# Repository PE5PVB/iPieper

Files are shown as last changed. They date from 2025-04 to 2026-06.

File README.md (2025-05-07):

# iPieper: Uitgebreide 2m FM vossenjacht zender

De iPieper is een laagvermogen PLL gestuurde FM-vossenjachtzender met WAV/MP3 geheugen. Ook kun je
verschillende instellingen programmeren, zoals hoe lang de zender ingeschakeld of uitgeschakeld moet zijn, welk
bestand moet worden afgespeeld en op welke frequentie er moet worden uitgezonden. Je kunt elke willekeurige
frequentie tussen 144 en 146MHz gebruiken in een raster van 25kHz. Het is ook mogelijk om de iPieper zelf een
frequentie te laten kiezen wanneer deze begint met uitzenden.

Ook is er een header aanwezig met een aantal GPIOs. Zo kun je bijvoorbeeld zelf sensoren aansluiten. De software en
hardware is geheel opensource dus naar gelieve aan te passen.

Programmeren gaat via het Bluetooth serial protocol. Wanneer de iPieper met bijvoorbeeld een Windows laptop via
bluetooth is verbonden zal er een virtuele COM-poort beschikbaar komen om deze te programmeren.

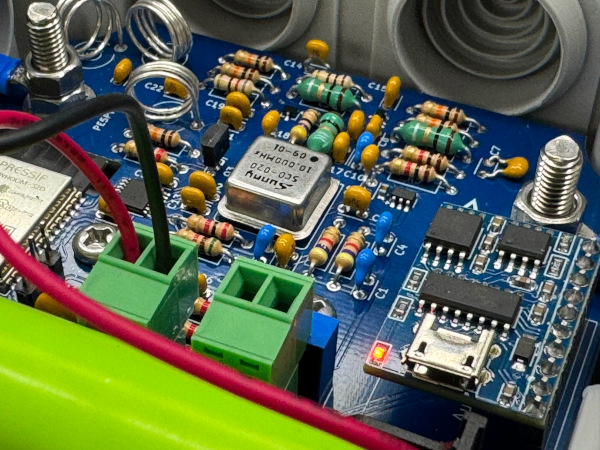
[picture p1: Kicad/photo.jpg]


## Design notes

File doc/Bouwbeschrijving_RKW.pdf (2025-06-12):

# Bouwproject iPieper

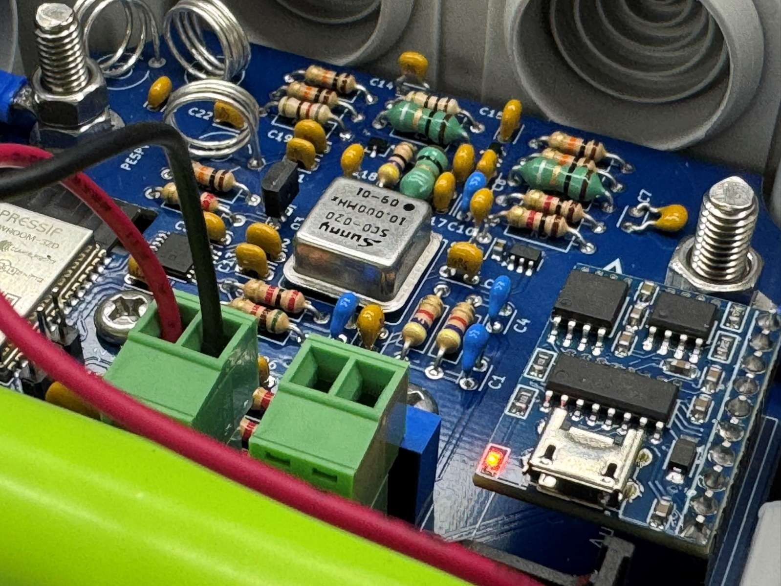
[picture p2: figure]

## VRZA Radiokampweek 2025

Sjef Verhoeven PE5PVB

## Inleiding

De iPieper is een laagvermogen PLL gestuurde FM-vossenjachtzender met WAV/MP3 geheugen. Ook kun je verschillende instellingen programmeren, zoals hoe lang de zender ingeschakeld of uitgeschakeld moet zijn, welk bestand moet worden afgespeeld en op welke frequene er moet worden uitgezonden. Je kunt elke willekeurige frequene tussen 144 en 146MHz gebruiken in een raster van 25kHz. Het is ook mogelijk om de iPieper zelf een frequene te laten kiezen wanneer deze begint met uitzenden.

Ook is er een header aanwezig met een aantal GPIOs. Zo kun je bijvoorbeeld zelf sensoren aansluiten. De soware en hardware is geheel opensource dus naar gelieve aan te passen.

Programmeren gaat via het Bluetooth serial protocol. Wanneer de iPieper met bijvoorbeeld een Windows laptop via bluetooth is verbonden zal er een virtuele COM-poort beschikbaar komen om deze te programmeren.

## Werking

Het 2-meter signaal wordt direct op frequene gegenereerd door U1, een oscillator die geïntegreerd is in een chip. Deze oscillator wordt aangestuurd door U2, het PLL IC. Na generae wordt het RF-signaal in twee stappen versterkt door Q1 en Q2, waarna het via een laagdoorlaailter naar de antenneklem wordt geleid. Terugkoppeling van het RF-signaal vindt plaats na de eerste buffertrap via C17, zodat de PLL een fasevergelijking kan uitvoeren. Op basis hiervan ontstaat een regelspanning die gefilterd wordt door het loopfilter, bestaande uit C1, C2, C3, R1 en R2. Het audiosignaal wordt via R3 en C4 gekoppeld aan deze regelspanning, wat resulteert in FM-modulae. Het niveau van dit audiosignaal is instelbaar met RV1, dat het signaal na een laagdoorlaailter (bestaande uit R18, R20, R21, C25 en C26) verwerkt.
De aansturing van de PLL wordt verzorgd door U3, een ESP32-module. Hoewel deze microcontroller in dit geval misschien wat overgekwalificeerd is, is hij zeer betaalbaar en bovendien voorzien van een ingebouwde Bluetoothmodule. Om het stroomverbruik te beperken, is de kloksnelheid tot een minimum gereduceerd. De ESP32 is ook in staat om een toon te genereren die gebruikt wordt in de “panic”-modus van de iPieper. Daarnaast schakelt hij via Q3, een FET, de gehele zender in of uit.
Voor de audio-opwekking wordt gebruikgemaakt van de JQ8400-FL module, die geplaatst wordt in J5. Wanneer je MP3- of WAV-bestanden wilt vervangen of toevoegen, moet deze module uit het voetje worden gehaald en rechtstreeks op een PC worden aangesloten. De module wordt dan herkend als een externe schijf. Ook deze audiomodule wordt aangestuurd door de ESP32.
De spanningsvoorziening is in handen van U4, een 3,3V spanningsregelaar met een uitzonderlijk lage dropoutspanning van maximaal 50 mV. Door J7 te overbruggen, kan de iPieper volledig worden uitgeschakeld.

## Verbinden via Bluetooth

Wanneer de iPieper in de programmeerstand is geschakeld (zie volgend hoofdstuk), kan deze worden verbonden via bluetooth. Met bijvoorbeeld een Windows laptop kun je rechtsonder (bij de klok) op het bluetooth icon klikken en kiezen om een nieuw apparaat toe te voegen. Tijdens het zoeken zal de iPieper worden herkend en wordt de naam van de iPieper getoond.

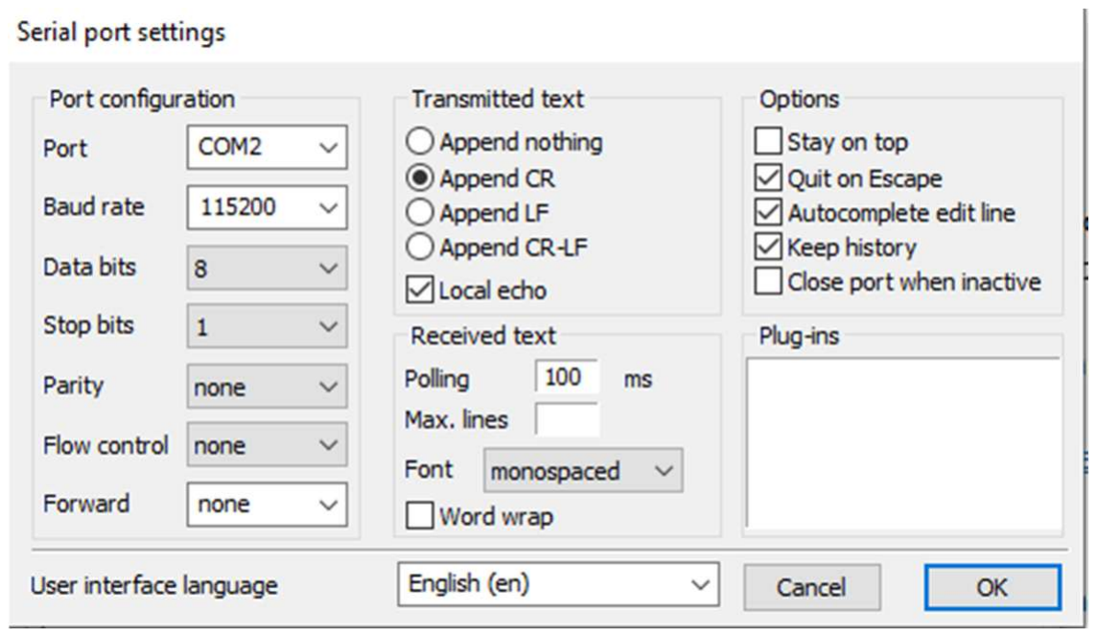
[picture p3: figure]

Nadat je verbinding hebt gemaakt wordt er een
virtuele seriële poort toegevoegd. Je kunt met een
serieel terminal programma eenvoudig verbinding maken. In dit voorbeeld wordt de gras tool Termite gebruikt. Deze kan worden gedownload op hps://www.compuphase.com/soware_termite.htm

Gebruik deze instellingen voor een correcte verbinding. Kies uiteraard wel de juiste COM-poort.

## Configurae

Wanneer de iPieper op spanning wordt gezet start deze op. Na ca. 2 seconden zal de PGM LED oplichten. Druk nu binnen 20 seconden op de PGM-schakelaar. De LED zal nu gaan knipperen. De zender van de iPieper zal worden uitgeschakeld en de configurae is via bluetooth beschikbaar.
Via een terminal programma kun je de volgende commando’s gebruiken:
? Toont het menu

F Voer zendfrequene in kHz in, gebruik een raster van 25kHz. Bijvoorbeeld <F145550>

A Geef aan hoelang de zender uitgeschakeld moet blijven voordat deze weer inschakelt in seconden,
| Bijvoorbeeld <A10>.

B Geef aan hoelang de zender ingeschakeld moet blijven in seconden. Bijvoorbeeld <A5>. Gebruik <A0> om de
| lengte van het MP3/WAV bestand aan te houden.

P Geef aan na hoeveel minuten de panic mode acef moet worden. Hierbij wordt de zender permanent
| ingeschakeld op 145.000MHz met een pieptoon en gaat de LED snel knipperen. Dit kan bijvoorbeeld handig zijn jdens het opruimen van een vossenjacht. Bijvoorbeeld: <P180>

N Geef de pieper een naam. Dan is deze eenvoudig te herkennen als bluetooth apparaat. Ook wordt de naam
| jdens het programmeren als prompt gebruikt. Bijvoorbeeld <NPieper 1>

T Test de huidige configurae.

R Schakel de terror mode in of uit. Hiermee wordt bij elke keer dat de zender in de lucht komt een willekeurige
| frequene gekozen.

M Geef aan welke MP3/WAV bestand je wilt afspelen. Bijvoorbeeld <M1>. Gebruik <M0> voor een willekeurig
| bestand.

L Toont een lijst van beschikbare MP3/WAV bestanden inclusief lengte

O Toont een overzicht van de huidige configurae

S Herstart de iPieper

Wijzigingen worden aljd direct opgeslagen. Het is dus niet nodig de iPieper te herstarten om de instellingen op te slaan.

## Bouw instruce

### 1. Begin met de lage componenten

Start met het plaatsen en solderen van de lage componenten: weerstanden, diodes, LED, 1 µH spoelen, kristaloscillator en headers. Vergeet niet de female header te monteren waarin later de JQ8400-module geplaatst wordt. Soldeer deze module dus niet direct vast op de printplaat!

### 2. Vervolg met de overige componenten

Ga vervolgens verder met de condensatoren (de waardes zijn gemarkeerd voor eenvoudige herkenning), de zelerstellende zekering, potenometer, FET en overige onderdelen.

### 3. Montage van de M5 boutjes

Bevesg de twee M5 boutjes ondersteboven in de printplaat, zodat het draadeind naar boven steekt. Zet elk boutje vast met één moer. De tweede moer gebruik je later om de antennedraad met een krimpoogje vast te zeen.

### 4. Spoelen wikkelen

Wikkel nu de spoelen. Ze moeten een diameter van 7 mm hebben. Gebruik hiervoor een boortje van 6 mm als wikkelhulp.

### 5. Behuizing monteren

Plaats de printplaat in de lasdoosbehuizing en bevesg deze met de twee M4 boutjes die bij het pakket geleverd zijn. Steek de JQ8400-module in de daarvoor bestemde female header en sluit de kabel van de baerijhouder aan. Let hierbij goed op de polariteit!

### 6. Soware laden

Als alles correct is gemonteerd en gecontroleerd, kun je nu de soware op het apparaat laden. De iPieper zou daarna direct moeten funconeren.

### 7. Antenne aansluiten

Knip twee stukken 1,5 mm² draad van elk ongeveer 50 cm. Krimp aan elk uiteinde een oogje. Steek de draden vanuit de binnenkant van de lasdoos naar buiten en bevesg de oogjes aan de M5 bouten op de print. Deze draden vormen de antenne.

### 8. Camouflage

Camoufleer de lasdoos zodat deze niet opvalt in de natuurlijke omgeving. Wees creaef. Als je de lasdoos wil gaan spuiten is het verstandig om eerst een goede primer aan te brengen, anders zal het spuitwerk snel loslaten.

Tip:
De J7-connector kan gebruikt worden als stand-by schakelaar. Je kunt hier bijvoorbeeld een cinch-chassisdeel op aansluiten. Wanneer je vervolgens een kortgesloten cinch-connector plaatst, schakelt de iPieper in stand-by. Let op: het stroomverbruik in stand-by is maximaal 5 µA. Laat de iPieper daarom niet wekenlang in stand-by staan, anders loopt de baerij langzaam leeg.

## Schema

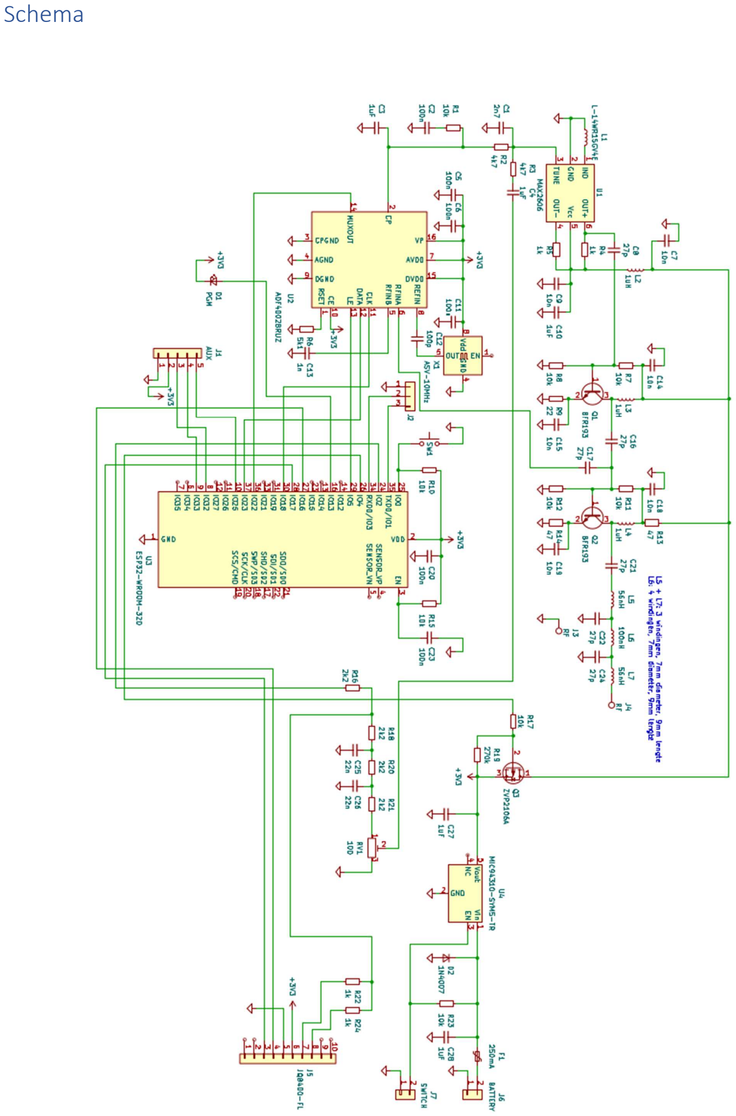
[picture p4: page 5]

## Componentenopstelling

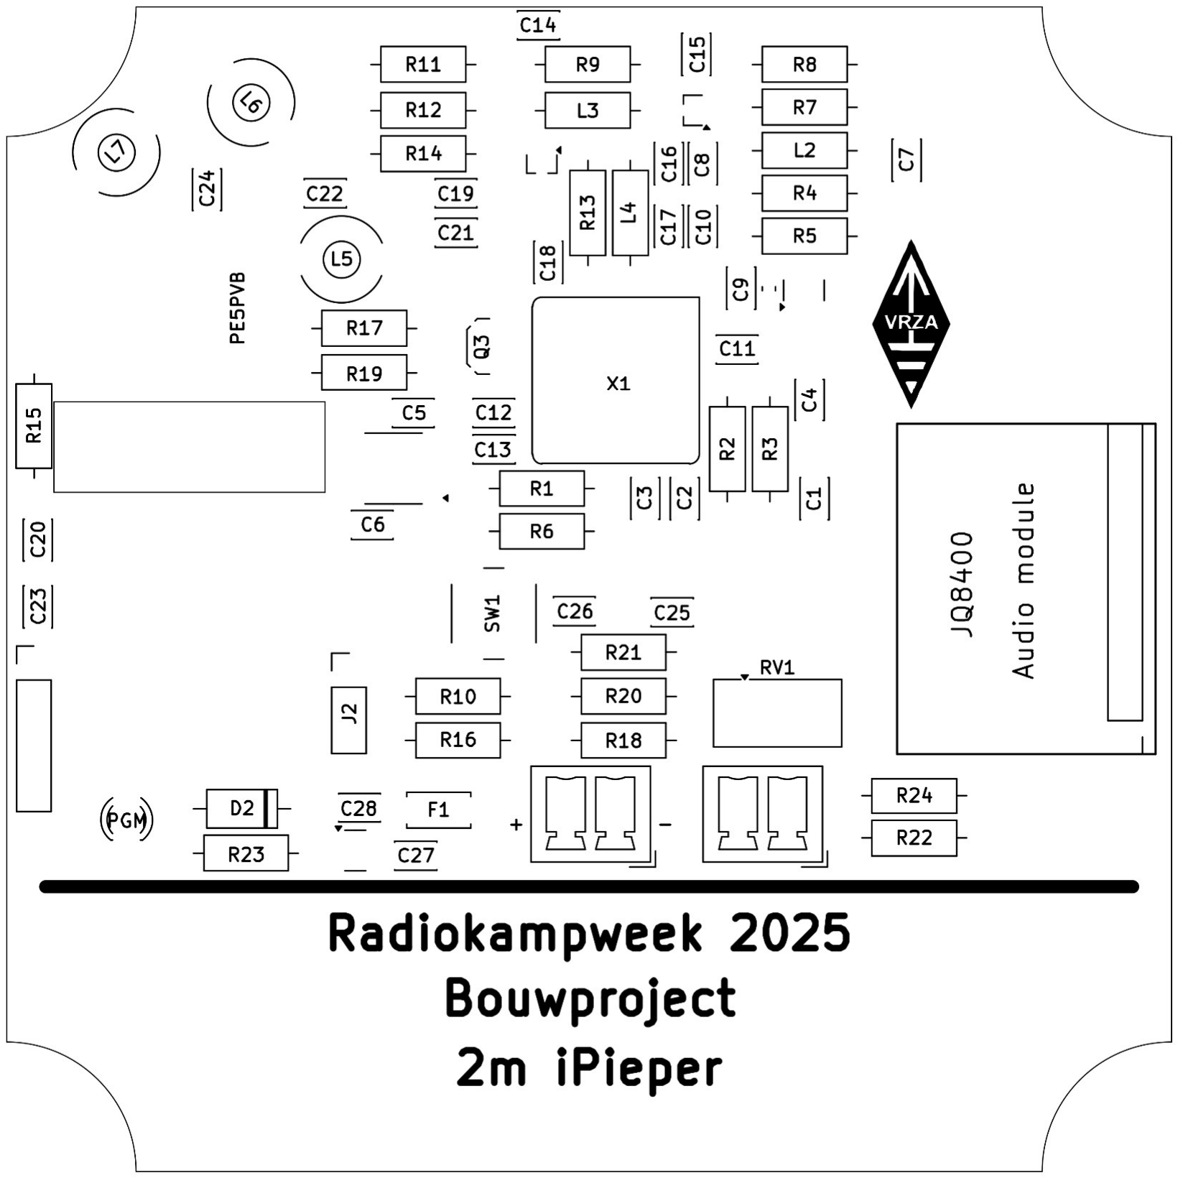
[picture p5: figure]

## Componentenlijst

Weerstanden
9x | R1, R7, R8, R10, R11, R12, R15, R17, R23 | 10k
4x | R4, R5, R22, R24 | 1k
4x | R16, R18, R20, R21 | 2k2
2x | R2, R3 | 4k7
1x | R1 | 2k
1x | R6 | 5k1
1x | R9 | 22Ω
2x | R13, R14 | 47Ω
1x | R19 | 270k

Condensatoren
6x | C2, C5, C6, C11, C20, C23 | 100n (104)
5x | C3, C4, C10, C27, C28 | 1uF | (105)
6x | C7, C9, C14, C15, C18, C19 | 10n | (103)
1x | C13 | 1n | (102)
1x | C12 | 100p (101)
6x | C8, C16, C17, C21, C22, C24 | 27p | (27j)
2x | C25, C26 | 22n | (223)
1x | C1 | 2n7 | (272)

Spoelen
3x | L2, L3, L4 | 1uH
2x | L5, L7 | 56nH (3 windingen ⌀9mm)
1x | L6 | 100nH (4 windingen ⌀9mm)

Overige
1x | D1 | LED
1x | D2 | 1N4007
1x | X1 | 10MHz oscillator
1x | F1 | Zelerstellende zekering 250mA
1x | SW1 | Drukknop
1x | Q3 | ZVP2106A
1x | RV1 | 100Ω meerslagen potenometer
2x | J3, J4 | RF aansluing M5
1x | J1 | 5 pins GPIO header
1x | J2 | 3 pins programmer header
1x | J5 | JQ8400-FL module
1x | J6 | Baerij aansluing
1x | J7 | Stand-by schakelaar aansluing

Al voor gemonteerd
1x | L1 | L-14WR15GV4E
1x | U1 | MAX2606
1x | U2 | ADF4002BRUZ
1x | U3 | ESP32-WROOM-32D
1x | U4 | MIC94310-SYM5-TR
2x | Q1, Q2 | BFR193

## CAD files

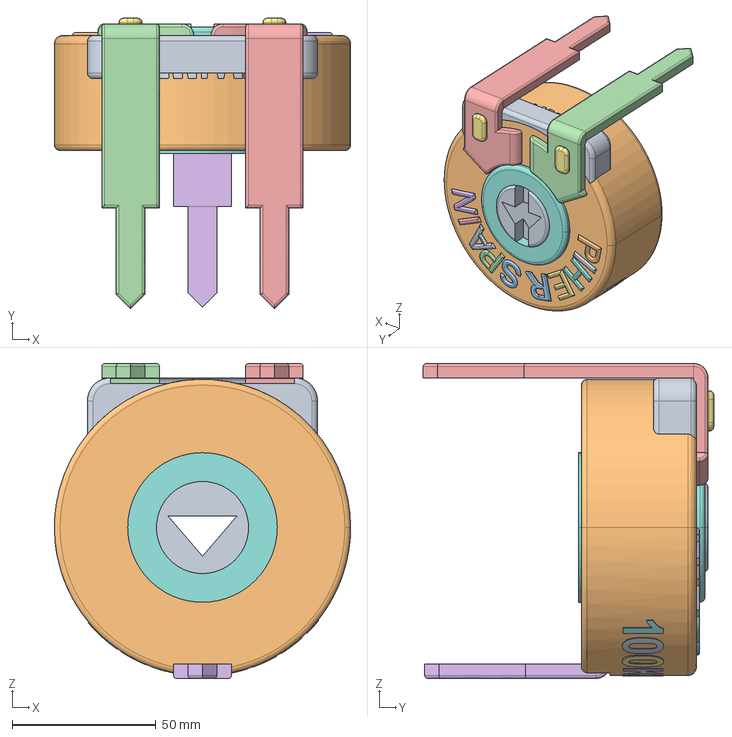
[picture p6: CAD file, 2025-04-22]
Kicad/PT-10.stp
103.0 x 101.0 x 109.5 mm

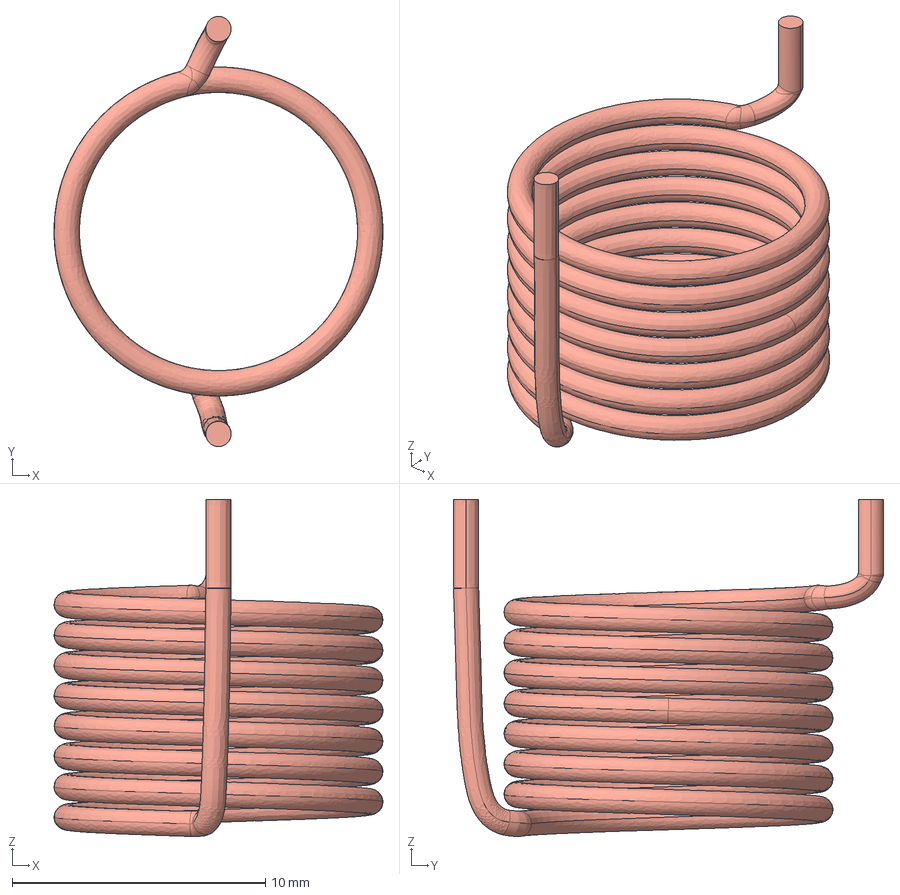
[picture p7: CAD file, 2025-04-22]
Kicad/coil.stp
13.0 x 17.0 x 13.3 mm

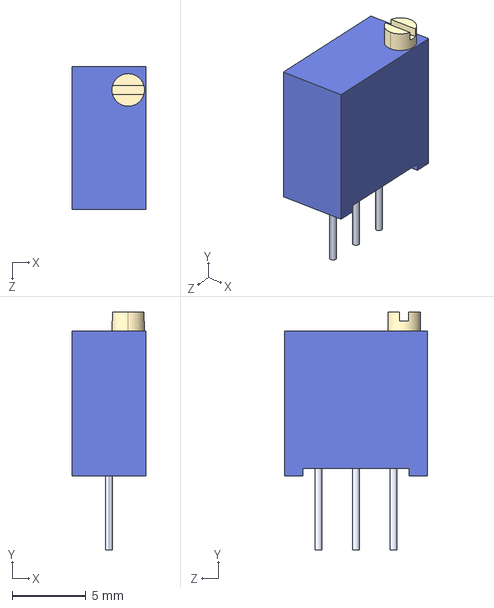
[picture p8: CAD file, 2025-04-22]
Kicad/T93YA101KT20.STEP
5.00 x 16.1 x 9.70 mm

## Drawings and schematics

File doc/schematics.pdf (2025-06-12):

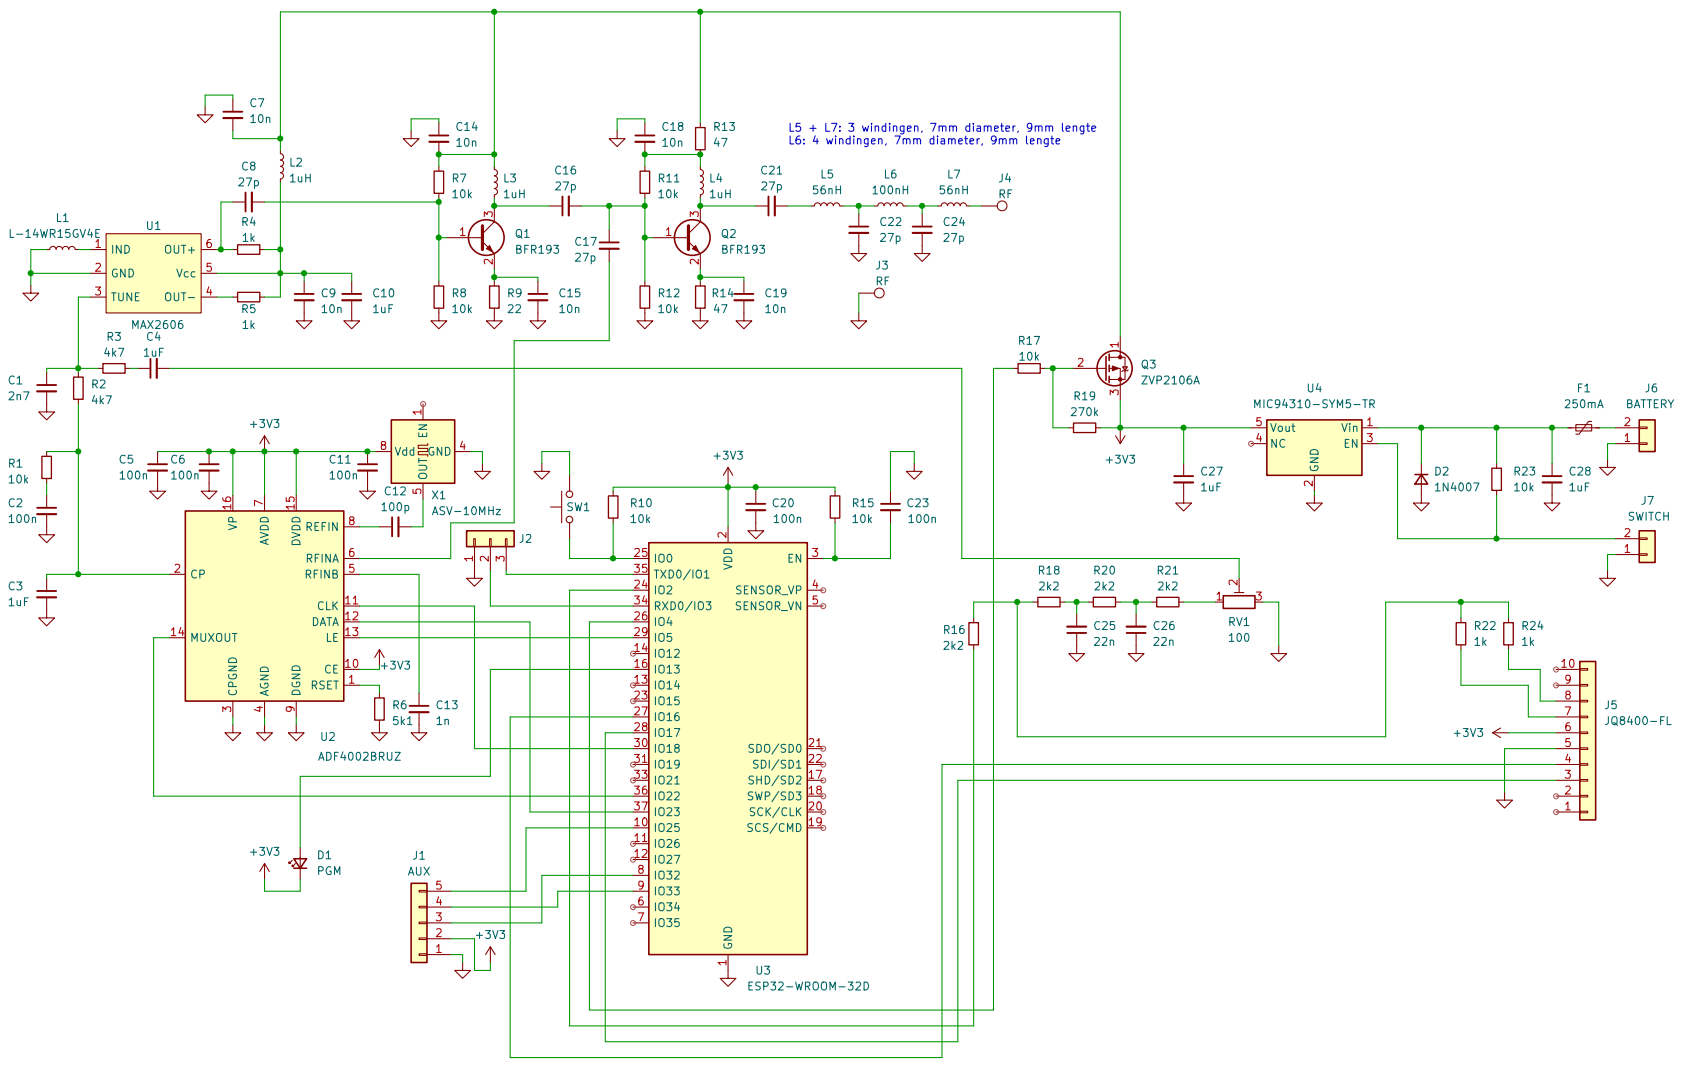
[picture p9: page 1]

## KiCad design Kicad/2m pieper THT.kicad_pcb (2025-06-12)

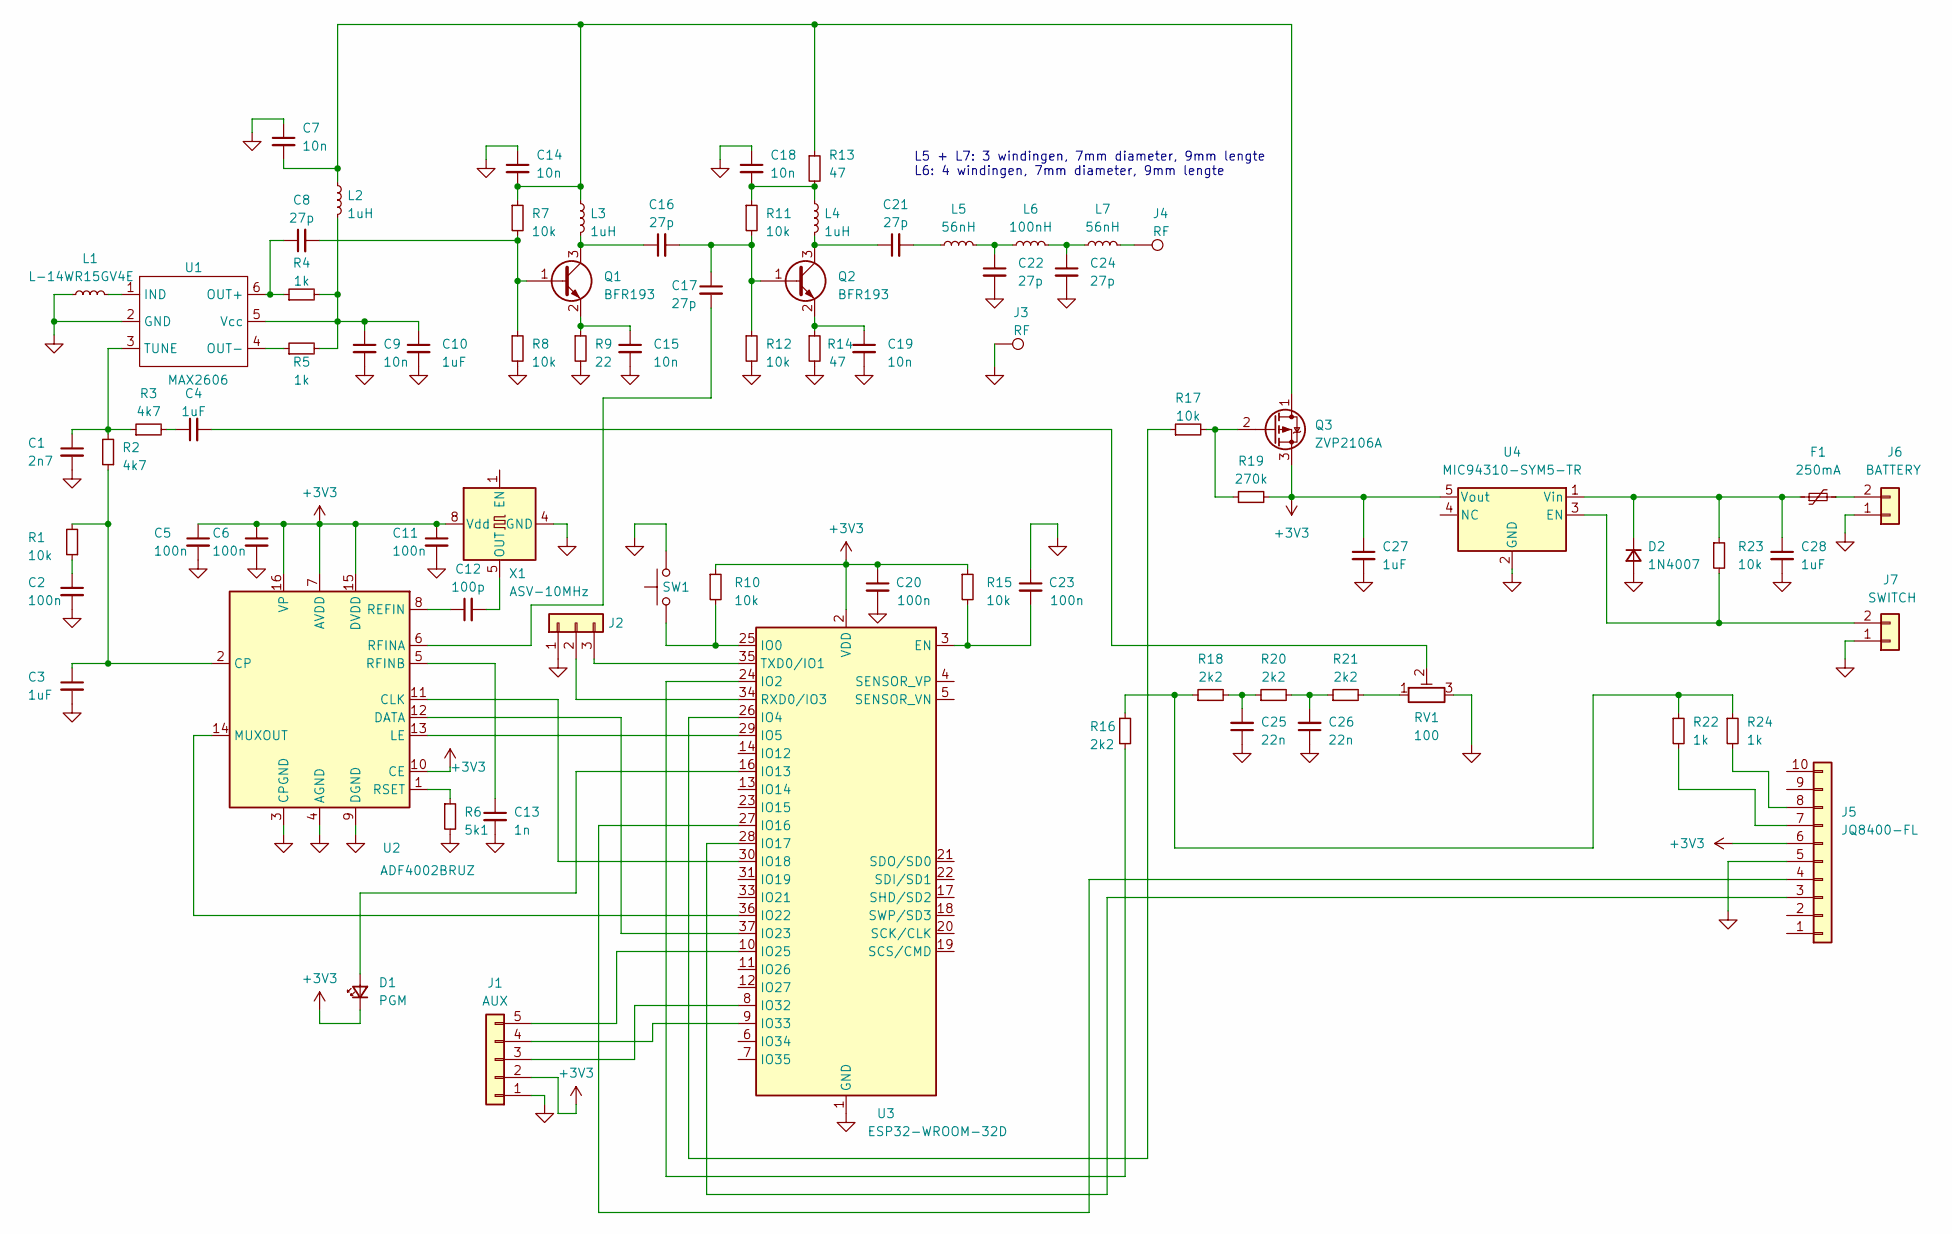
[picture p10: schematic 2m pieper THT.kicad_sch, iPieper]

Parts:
C1: 2n7; C_Disc_D3.0mm_W2.0mm_P2.50mm
C2, C5, C6, C11, C20, C23: 100n; C_Disc_D3.0mm_W2.0mm_P2.50mm
C3, C4, C10, C27, C28: 1uF; C_Disc_D3.0mm_W2.0mm_P2.50mm
C7, C9, C14, C15, C18, C19: 10n; C_Disc_D3.0mm_W2.0mm_P2.50mm
C8, C16, C17, C21, C22, C24: 27p; C_Disc_D3.0mm_W2.0mm_P2.50mm
C12: 100p; C_Disc_D3.0mm_W2.0mm_P2.50mm
C13: 1n; C_Disc_D3.0mm_W2.0mm_P2.50mm
C25, C26: 22n; C_Disc_D3.0mm_W2.0mm_P2.50mm
D1: PGM; LED_D3.0mm_FlatTop
D2: 1N4007; D_DO-41_SOD81_P10.16mm_Horizontal
F1: 250mA; C_Disc_D4.7mm_W2.5mm_P5.00mm
J1: AUX; PinHeader_1x05_P2.54mm_Vertical
J2: 1x3 header; PinHeader_1x03_P2.54mm_Vertical
J3, J4: RF; MountingHole_5.3mm_M5_Pad_Via
J5: JQ8400-FL; PinHeader_1x10_P2.54mm_Vertical
J6: BATTERY; PhoenixContact_MCV_1,5_2-G-3.81_1x02_P3.81mm_Vertical
J7: SWITCH; PhoenixContact_MCV_1,5_2-G-3.81_1x02_P3.81mm_Vertical
L1: L-14WR15GV4E; L_0603_1608Metric
L2, L3, L4: 1uH; R_Axial_DIN0207_L6.3mm_D2.5mm_P10.16mm_Horizontal
L5, L7: 56nH; L_Toroid_Horizontal_D6.5mm_P10.00mm_Diameter7-5mm_Amidon-T25
L6: 100nH; L_Toroid_Horizontal_D6.5mm_P10.00mm_Diameter7-5mm_Amidon-T25
Q1, Q2: BFR193; SOT-323_SC-70
Q3: ZVP2106A; TO-92Flat
R1, R7, R8, R10, R11, R12, R15, R17, R23: 10k; R_Axial_DIN0207_L6.3mm_D2.5mm_P10.16mm_Horizontal
R2, R3: 4k7; R_Axial_DIN0207_L6.3mm_D2.5mm_P10.16mm_Horizontal
R4, R5, R22, R24: 1k; R_Axial_DIN0207_L6.3mm_D2.5mm_P10.16mm_Horizontal
R6: 5k1; R_Axial_DIN0207_L6.3mm_D2.5mm_P10.16mm_Horizontal
R9: 22; R_Axial_DIN0207_L6.3mm_D2.5mm_P10.16mm_Horizontal
R13, R14: 47; R_Axial_DIN0207_L6.3mm_D2.5mm_P10.16mm_Horizontal
R16, R18, R20, R21: 2k2; R_Axial_DIN0207_L6.3mm_D2.5mm_P10.16mm_Horizontal
R19: 270k; R_Axial_DIN0207_L6.3mm_D2.5mm_P10.16mm_Horizontal
RV1: 100; Potentiometer_Vishay_T93YA_Vertical
SW1: SW_Push; SW_PUSH_6mm
U1: MAX2606; SOT-23-6
U2: ADF4002BRUZ; TSSOP-16_4.4x5mm_P0.65mm
U3: ESP32-WROOM-32D; ESP32-WROOM-32E
U4: MIC94310-SYM5-TR; SOT-23-5
X1: ASV-10MHz; Oscillator_DIP-8_LargePads

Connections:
+3V3: C5.1, C6.1, C11.1, C20.1, C27.1, D1.1 (K), J1.2, J5.6, Q3.3 (S), R10.1, R15.1, R19.2, U2.7 (AVDD), U2.10 (CE), U2.15 (DVDD), U2.16 (VP), U3.2 (VDD), U4.5 (Vout), X1.8 (Vdd)
GND: C1.2, C2.2, C3.2, C5.2, C6.2, C7.1, C9.2, C10.2, C11.2, C13.2, C14.1, C15.2, C18.1, C19.2, C20.2, C22.2, C23.1, C24.2, C25.1, C26.1, C27.2, C28.2, D2.2 (A), J1.1, J2.1, J3.1, J5.5, J6.1, J7.1, L1.1, R6.2, R8.2, R9.2, R12.2, R14.2, RV1.3, SW1.2, U1.2 (GND), U2.3 (CPGND), U2.4 (AGND), U2.9 (DGND), U3.1 (GND), U3.15 (GND), U3.38 (GND), U3.39 (GND), U4.2 (GND), X1.4 (GND)
unnamed: C2.1, R1.1
unnamed: C4.1, R3.2
unnamed: C4.2, RV1.2
unnamed: C18.2, L4.1, R11.1, R13.2
unnamed: C21.2, L5.1
unnamed: C22.1, L5.2, L6.1
unnamed: C24.1, L6.2, L7.1
unnamed: C25.2, R18.2, R20.1
unnamed: C26.2, R20.2, R21.1
unnamed: D1.2 (A), U3.16 (IO13)
unnamed: C28.1, D2.1 (K), F1.1, R23.1, U4.1 (Vin)
unnamed: J1.3, U3.8 (IO32)
unnamed: J1.4, U3.9 (IO33)
unnamed: J1.5, U3.10 (IO25)
unnamed: J2.2, U3.34 (RXD0/IO3)
unnamed: J2.3, U3.35 (TXD0/IO1)
unnamed: J4.1, L7.2
unnamed: J5.3, U3.28 (IO17)
unnamed: J5.4, U3.27 (IO16)
unnamed: J5.7, R22.2
unnamed: J5.8, R24.2
unnamed: F1.2, J6.2
unnamed: J7.2, R23.2, U4.3 (EN)
unnamed: C8.2, Q1.1 (B), R7.2, R8.1
unnamed: C16.1, L3.2, Q1.3 (C)
unnamed: C15.1, Q1.2 (E), R9.1
unnamed: C16.2, C17.1, Q2.1 (B), R11.2, R12.1
unnamed: C21.1, L4.2, Q2.3 (C)
unnamed: C19.1, Q2.2 (E), R14.1
unnamed: C7.2, C14.2, L2.1, L3.1, Q3.1 (D), R7.1, R13.1
unnamed: Q3.2 (G), R17.2, R19.1
unnamed: R16.1, R18.1, R22.1, R24.1
unnamed: R21.2, RV1.1
unnamed: L1.2, U1.1 (IND)
unnamed: C8.1, R4.1, U1.6 (OUT+)
unnamed: R5.1, U1.4 (OUT-)
unnamed: C1.1, R2.2, R3.1, U1.3 (TUNE)
unnamed: C9.1, C10.1, L2.2, R4.2, R5.2, U1.5 (Vcc)
unnamed: U2.11 (CLK), U3.30 (IO18)
unnamed: C3.1, R1.2, R2.1, U2.2 (CP)
unnamed: U2.12 (DATA), U3.37 (IO23)
unnamed: U2.13 (LE), U3.29 (IO5)
unnamed: U2.14 (MUXOUT), U3.36 (IO22)
unnamed: C12.1, U2.8 (REFIN)
unnamed: C17.2, U2.6 (RFINA)
unnamed: C13.1, U2.5 (RFINB)
unnamed: R6.1, U2.1 (RSET)
unnamed: C23.2, R15.2, U3.3 (EN)
unnamed: R10.2, SW1.1, U3.25 (IO0)
unnamed: R16.2, U3.24 (IO2)
unnamed: R17.1, U3.26 (IO4)
unnamed: C12.2, X1.5 (OUT)

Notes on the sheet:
L5 + L7: 3 windingen, 7mm diameter, 9mm lengte L6: 4 windingen, 7mm diameter, 9mm lengte

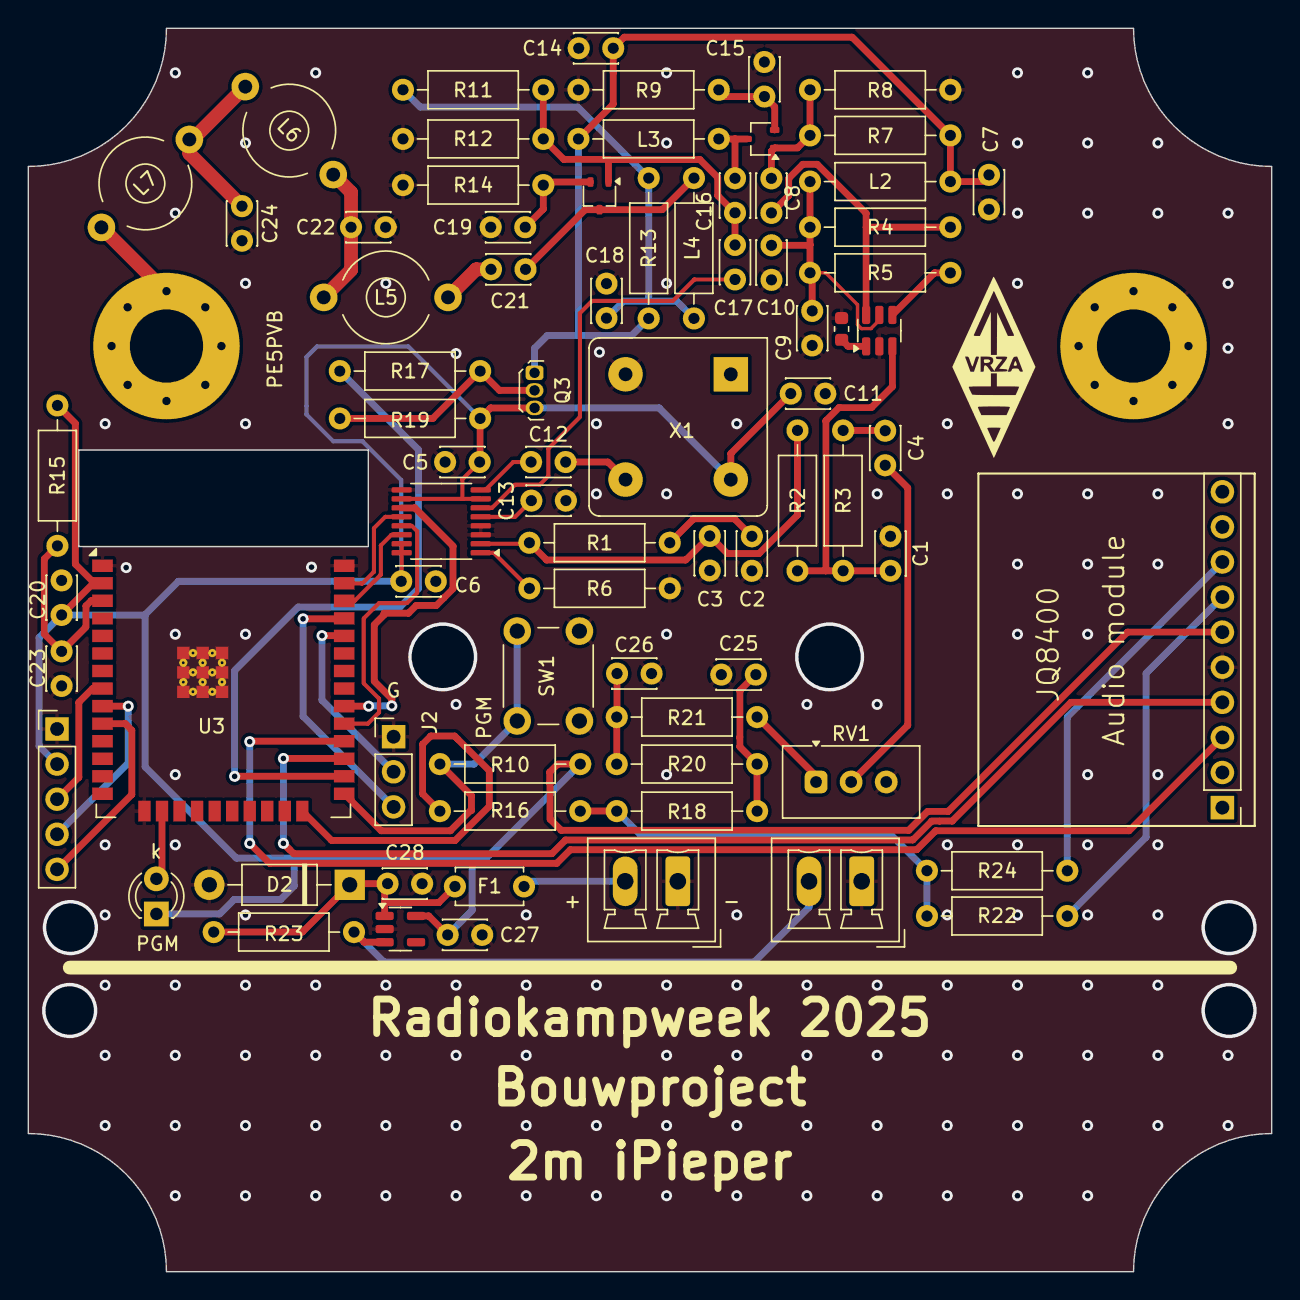
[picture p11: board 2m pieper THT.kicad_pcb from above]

Board: 2 copper layers, 90.0 x 90.0 mm, 79 parts (0 on the bottom side), 54 nets.

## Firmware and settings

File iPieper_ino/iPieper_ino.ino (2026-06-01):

/*
  iPieper software v1.0

  Te bouwen met:
    - Arduino IDE : open iPieper_ino.ino
    - VS Code     : open de map iPieper_ino (PlatformIO, zie platformio.ini)

  Compileert op zowel arduino-esp32 core 2.x als 3.x: de ledc-API in panic
  mode switcht automatisch via #if ESP_ARDUINO_VERSION_MAJOR >= 3.

  Instellingen voor een zo laag mogelijk stroomverbruik. In de Arduino IDE
  stel je deze in via het Tools-menu; bij PlatformIO staan ze al in
  platformio.ini. Bovendien zet setup() de klok zelf op 80 MHz, zodat de
  lage kloksnelheid in beide omgevingen gegarandeerd is:

  CPU Frequency                80MHz (laagste klok waarbij Bluetooth blijft werken)
  Flash frequency              40MHz
*/

#include "soc/soc.h"
#include "soc/rtc_cntl_reg.h"
#include <SPI.h>
#include <JQ8400_Serial.h>
#include <EEPROM.h>
#include <BluetoothSerial.h>
#include <Update.h>
#include "mbedtls/base64.h"
#include "esp_bt.h"          // esp_bredr_tx_power_set()
#include "nvs_flash.h"       // nvs_flash_erase() voor #FACTORYRESET

BluetoothSerial SerialBT;
JQ8400_Serial mp3(Serial2);

bool                  bootEnd = false;
bool                  config = false;
bool                  ledState = false;
bool                  terrormode = false;
bool                  testmode = false;
bool                  txonoffstate = true;
byte                  mp3track = 0;
byte                  previousTrack = 255;
byte                  txoff = 0;
byte                  txon = 0;
char                  piepername[11];
byte                  audioMode = 0;        // 0 = MP3 via JQ8400, 1 = morse, 2 = Nokia ringtone
byte                  morseWpm = 6;         // 3..12 WPM (PARIS-norm)
char                  morseText[31];        // max 30 chars + null
byte                  morseAmp = 5;         // 1..10 stap; geldt voor morse EN ringtone
byte                  ringTrack = 1;        // 1..10, geselecteerde ringtone slot
char                  ringBuf[251];         // tijdelijke buffer voor slot-load; max == EE_RINGSLOT_SIZE
const unsigned long   bootTime = 120000;     // config-venster bij boot (2 min)
const unsigned long   longPressMs = 2000;     // drempel voor lang-indrukken (TX-kill)
String                inputBuffer = "";
unsigned int          frequency = 145000;
unsigned int          numberoffiles;
unsigned int          panictime = 0;
unsigned long         ledMillis = 0;
unsigned long         txonoffMillis = 0;

// OTA-state (BT-OTA via het #-protocol). otaActive=true zolang er een
// transfer loopt; tijdens die periode wordt de TX-cyclus uitgezet om
// flash-writes niet te storen.
bool                  otaActive = false;
unsigned long         otaBytesReceived = 0;
unsigned long         otaExpectedSize = 0;

typedef struct {
  unsigned int  index;
  char          name[120];
  unsigned int  length;
} FileLibrary;

FileLibrary file[50];

#define RF_TX                       4
#define pin_LE                      5
#define pin_Audio                   2
#define pin_Button                  0
#define pin_LED                     13

#define EE_TOTAL_CNT                2567   // 57 + 10*251 (RINGSLOTS). 10 slots is
                                            // de stabiele max binnen de standaard 20 KB
                                            // NVS-partitie van min_spiffs.csv. Meer
                                            // vereist een custom partition table met
                                            // grotere NVS - alleen via USB-flash.
#define EE_CHECKNUMBER              12

#define EE_UINT16_FREQUENCY         0
#define EE_UINT16_PANICTIME         4
#define EE_BYTE_TXOFF               8
#define EE_BYTE_TXON                9
#define EE_BYTE_MP3TRACK            10
#define EE_BYTE_TERRORMODE          11
#define EE_CHECK                    12
#define EE_BYTE_PIEPERNAME          13    // 10 posities
#define EE_BYTE_AUDIOMODE           23    // 0 = MP3 (JQ8400), 1 = morse, 2 = Nokia ringtone
#define EE_BYTE_MORSEWPM            24    // 3-12 WPM
#define EE_BYTE_MORSETEXT           25    // 30 posities (+ null)
#define EE_BYTE_MORSEAMP            55    // 1-10 stap (geldt voor morse EN ringtone)
#define EE_BYTE_RINGTRACK           56    // 1..10, geselecteerde ringtone slot
#define EE_BYTE_RINGSLOTS           57    // 10 slots * 251 bytes = 2510 bytes
                                          // elk slot: "tempo,notes" string (max 250 + null)
#define EE_RINGSLOT_SIZE            251

// GUI-protocol (over Bluetooth, prefix '#'): firmware- en protocolversie
// teruggegeven door #V?. Pre-release: we bumpen nog NIET per kleine wijziging
// omdat er nog geen Windows-tool in het wild zit die op een specifiek nummer
// vertrouwt. Bump pas bij echte release, of als een breaking change in de
// wire-API een client moet kunnen detecteren.
//
// Huidig command-surface (proto=2):
//   V?          -> #V: fw=...;proto=...;build=...
//   GET         -> #CFG: name=...;freq=...;...;audiomode=0/1/2;morsewpm=...;
//                       morseamp=...;ringtrack=1..10;morsetext=...
//   SET key=val -> #OK: <key>=<val>  of  #ERR: <reason>
//                  keys: name, freq, txon, txoff, mp3, terror, test, panic,
//                        audiomode, morsewpm, morsetext, morseamp, ringtrack,
//                        ringslot<N>  (N=1..10, strict RTTTL "name:defaults:notes",
//                        naam max 20 chars)
//   LIST        -> #TRK: index=...;name=...  (× N MP3-tracks van JQ8400) + #END
//   RTLIST      -> #RTSLOT: n=<N>;data=<rtttl>  (× 50, lege als data=) + #END
//   GETDEFAULT <n> -> #RTDEFAULT: n=<n>;data=<rtttl>  (slot 1-10 klassiekers,
//                     1-10) of #ERR: slot 1..10
//   OTA?, OTA START/D/END/ABORT -> #OTA: ... / #OK / #ERR
//   RST         -> herstart pieper
#define FW_VERSION                  "1.10"
#define GUI_PROTO_VERSION           2

void dbg(const String& s) {
  Serial.print('[');
  Serial.print(millis());
  Serial.print("] ");
  Serial.println(s);
}

void setup() {
  setCpuFrequencyMhz(80);                 // Laagste klok waarbij Bluetooth blijft werken (stroombesparing)
  WRITE_PERI_REG(RTC_CNTL_BROWN_OUT_REG, 0);
  Serial.begin(115200);
  Serial2.begin(9600);

  pinMode(RF_TX, OUTPUT);
  pinMode(pin_LE, OUTPUT);
  pinMode(pin_LED, OUTPUT);
  pinMode(pin_Button, INPUT);
  digitalWrite(pin_LED, HIGH);

  doTXEnable(0);

  EEPROM.begin(EE_TOTAL_CNT);
  if (EEPROM.readByte(EE_CHECK) != EE_CHECKNUMBER) Defaultsettings();
  frequency = EEPROM.readUInt(EE_UINT16_FREQUENCY);
  panictime = EEPROM.readUInt(EE_UINT16_PANICTIME);
  txoff = EEPROM.readByte(EE_BYTE_TXOFF);
  txon = EEPROM.readByte(EE_BYTE_TXON);
  mp3track = EEPROM.readByte(EE_BYTE_MP3TRACK);
  terrormode = EEPROM.readByte(EE_BYTE_TERRORMODE);

  for (byte x = 0; x < 10; x++) piepername[x] = EEPROM.read(EE_BYTE_PIEPERNAME + x);

  // Nieuwere settings: clamp/validate omdat oude EEPROM 0xFF of mesh-data
  // op deze offsets kan bevatten (zie git-historie).
  audioMode = EEPROM.readByte(EE_BYTE_AUDIOMODE);
  if (audioMode > 2) audioMode = 0;        // clamp; 0=MP3, 1=morse, 2=ringtone

  morseWpm = EEPROM.readByte(EE_BYTE_MORSEWPM);
  if (morseWpm < 3 || morseWpm > 12) morseWpm = 6;
  for (byte x = 0; x < 30; x++) morseText[x] = EEPROM.read(EE_BYTE_MORSETEXT + x);
  morseText[30] = '\0';
  // Trim op eerste 0xFF (= niet-geinitialiseerde flash); default als leeg.
  for (byte x = 0; x < 30; x++) {
    if ((byte)morseText[x] == 0xFF) { morseText[x] = '\0'; break; }
  }
  if (morseText[0] == '\0') strcpy(morseText, "CQ");

  morseAmp = EEPROM.readByte(EE_BYTE_MORSEAMP);
  if (morseAmp < 1 || morseAmp > 10) morseAmp = 5;   // clamp; oude waarden (50/100/0xFF) -> default

  ringTrack = EEPROM.readByte(EE_BYTE_RINGTRACK);
  if (ringTrack < 1 || ringTrack > 10) ringTrack = 1;

  // Migratie: vul alle 10 slots met de default RTTTL-klassiekers (getRtDefault)
  // als ze leeg, uninitialized, Nokia-format, of v1.8-test zijn. User RTTTL-
  // customizations blijven respecteerd (alleen lege/foute slots krijgen default).
  bool needCommit = false;
  char migBuf[EE_RINGSLOT_SIZE];
  for (byte s = 1; s <= 10; s++) {
    loadRingSlot(s, migBuf, sizeof(migBuf));
    bool isEmpty   = (migBuf[0] == '\0');                              // ook 0xFF -> '\0'
    bool isNokia   = (!isEmpty && strchr(migBuf, ':') == nullptr);
    bool isV18Test = (strncmp(migBuf, "007 Tune:", 9) == 0);            // oude v1.8 default
    const char* def = getRtDefault(s);
    if (isEmpty && def[0] == '\0') continue;                            // beide leeg: niets doen
    if (isEmpty || isNokia || isV18Test) {
      saveRingSlot(s, def);
      needCommit = true;
      dbg("Migratie: slot " + String(s) + " -> default");
    }
  }
  if (needCommit) EEPROM.commit();

  Serial.println();
  Serial.println(String(piepername) + " opstarten..........");

  SPI.begin();
  mp3.reset();
  mp3.setVolume(30);
  numberoffiles = mp3.countFiles();
  if (numberoffiles > 49) numberoffiles = 49;   // file[] heeft 50 plekken; we gebruiken 1..49

  for (int x = 1; x < numberoffiles + 1; x++) {
    mp3.playFileByIndexNumber(x);
    file[x].index = x;
    mp3.currentFileName(file[x].name, sizeof(file[x].name));
    file[x].length = mp3.currentFileLengthInSeconds();
  }

  mp3.sleep();
  txonoffMillis = millis();
  digitalWrite(pin_LED, LOW);
  dbg("Opstarten voltooid (txon=" + String(txon) + " txoff=" + String(txoff) + " freq=" + String(frequency) + ")");
}

void loop() {
  if (millis() < bootTime && !config) {
    blinkLED(250);                          // signaal: config-venster open
    if (digitalRead(pin_Button) == LOW) {
      // Knop ingedrukt: meten hoe lang. Twee mogelijke uitkomsten:
      //   - Loslaten < longPressMs  -> CONFIG-mode (BT activeren)
      //   - Vasthouden >= longPressMs -> TX UIT zolang vastgehouden,
      //                                  bij loslaten direct TX AAN + cyclus
      //                                  vanaf het begin van een TX-ON fase
      unsigned long pressStart = millis();
      bool longPress = false;
      while (digitalRead(pin_Button) == LOW) {
        if (!longPress && (millis() - pressStart >= longPressMs)) {
          longPress = true;
          doTXEnable(0);
          digitalWrite(pin_LED, HIGH);      // continu brand = "TX kill actief"
          dbg("Knop >= 2s ingedrukt - TX UIT (kill switch)");
        }
        delay(10);
      }

      if (longPress) {
        // Loslaten na lange druk: direct in de lucht, cyclus herstart vanaf
        // de TX-ON fase met audio. txonoffstate=true zorgt dat de cyclus-state
        // machine in zijn ON-helft staat; txonoffMillis=now reset de timer.
        dbg("Knop losgelaten - TX AAN, cyclus herstart");
        doTXEnable(1);
        txonoffstate = true;
        txonoffMillis = millis();
      } else {
        // Korte druk: config-mode (huidige gedrag).
        config = true;
        testmode = false;
        doTXEnable(0);
        dbg("Configuratie gestart");
        SerialBT.begin(piepername);
        // Verlaag BT TX-power van default +9 dBm naar 0 dBm (1 mW). Kleinere
        // stroompieken op de 3.3 V rail = minder kans op PLL/PA-storing. Moet
        // NA SerialBT.begin() omdat de controller dan pas geinitialiseerd is.
        esp_bredr_tx_power_set(ESP_PWR_LVL_N0, ESP_PWR_LVL_N0);
        dbg("BT TX-power gezet op 0 dBm (1 mW)");
        digitalWrite(pin_LED, HIGH);
      }
    }
  } else if (!bootEnd) {
    bootEnd = true;
    digitalWrite(pin_LED, HIGH);
    dbg("Boot venster afgelopen");
  }

  if (millis() >= (unsigned long)panictime * 60UL * 1000UL) {
    if (config) SerialBT.println("Panic mode aktief!");
    dbg("Panic mode aktief!");
    frequency = 145000;
    mp3.sleep();
    doTXEnable(1);
    pinMode(pin_Audio, OUTPUT);
#if ESP_ARDUINO_VERSION_MAJOR >= 3
    // arduino-esp32 3.x: pin-based ledc API
    ledcAttach(pin_Audio, 1000, 8);
    ledcWriteTone(pin_Audio, 1000);
    ledcWrite(pin_Audio, 50);
#else
    // arduino-esp32 2.x: channel-based ledc API
    ledcAttachPin(pin_Audio, 0);
    ledcWriteTone(0, 1000);
    ledcWrite(0, 50);
#endif
    while (true) blinkLED(500);
  }

  // Cyclus (toggle + TX/MP3) draait alleen wanneer we niet in pure config-
  // mode zitten en geen OTA-transfer bezig is. Test mode tijdens config
  // laat hem wel doorgaan zodat je de configuratie kunt verifieren. Zonder
  // deze guard zou de bookkeeping in config-mode blijven flippen en zou
  // een TX-aktie midden in een OTA-flashwrite vallen.
  if ((!config || testmode) && !otaActive) {
    // Bepaal de actieve audio-duur in ms (i.p.v. afgeronde seconden). Met
    // seconden-precisie was audioLenSec bij morse tot ~1 sec hoger dan wat
    // playMorse() werkelijk blokkeerde, waardoor de toggle niet vuurde toen
    // morse terugkwam -> de restart-if pakte morse opnieuw en het bericht
    // werd 2x per ON-fase geseind. Met ms-precisie vuurt de toggle exact
    // wanneer playMorse retour komt.
    unsigned long audioLenMs;
    if (audioMode == 1) {
      // Morse audio + 1 sec pre-roll + 1 sec post-roll (zie playMorse).
      audioLenMs = morseDurationMs(morseText, morseWpm) + 2000UL;
    } else if (audioMode == 2) {
      // Laad geselecteerd slot, dispatch op format (Nokia tempo,notes of RTTTL).
      loadRingSlot(ringTrack, ringBuf, sizeof(ringBuf));
      if (ringBuf[0] == '\0') {
        audioLenMs = 2000UL;
      } else {
        audioLenMs = slotDurationMs(ringBuf) + 2000UL;
      }
    } else {
      unsigned int mp3LenSec = (txon == 0) ? mp3.currentFileLengthInSeconds() : 0;
      if (mp3LenSec == 0 && txon == 0 && numberoffiles >= 1) {
        byte t = previousTrack;
        if (t < 1 || t > numberoffiles || t >= 50) {
          t = (mp3track >= 1 && mp3track <= numberoffiles) ? mp3track : (byte)1;
        }
        mp3LenSec = file[t].length;
      }
      audioLenMs = (unsigned long)mp3LenSec * 1000UL;
    }
    unsigned long needed = txonoffstate
                            ? (txon == 0 ? audioLenMs : (unsigned long)txon * 1000UL)
                            : (unsigned long)txoff * 1000UL;
    if (millis() >= txonoffMillis + needed) {
      unsigned long phaseMs = millis() - txonoffMillis;
      txonoffMillis = millis();
      txonoffstate = !txonoffstate;
      dbg(String("Toggle -> ") + (txonoffstate ? "ON" : "OFF") + " (vorige fase " + String(phaseMs) + " ms, audio=" + (audioMode == 1 ? "morse" : (audioMode == 2 ? "melody" : "mp3")) + " len=" + String(audioLenMs) + "ms, txon=" + String(txon) + " txoff=" + String(txoff) + ")");
      if (!txonoffstate && txoff != 0) {
        doTXEnable(0);
        if (config) SerialBT.println("TX UIT");
      }
    }

    if (txonoffstate) {
      if (audioMode == 1) {
        // Morse: playMorse blokkeert tot tekst af is. De volgende loop-iter
        // doet de toggle naar OFF (txon=0) of speelt opnieuw af (txon > duur).
        dbg("Morse start: \"" + String(morseText) + "\" (" + String(morseWpm) + " WPM)");
        if (config) SerialBT.println("TX AAN (morse)");
        doTXEnable(1);
        // SerialBT.flush() forceert dat de lokale BT-TX-buffer (waarin print/
        // println eerst hun bytes verzamelen tot MTU-grootte) nu daadwerkelijk
        // de send-queue in gaat - anders blijven kleine responses zoals
        // "#OK: test=1" achter en ziet de Windows-app pas na de morse iets.
        if (config) SerialBT.flush();
        playMorse(morseText, morseWpm);
      } else if (audioMode == 2) {
        loadRingSlot(ringTrack, ringBuf, sizeof(ringBuf));
        if (ringBuf[0] == '\0') {
          dbg("Slot " + String(ringTrack) + " is leeg, geen audio deze cyclus");
          // TX uit laten staan, cyclus loopt door op audioLenMs=2000.
        } else {
          dbg("RTTTL start: slot=" + String(ringTrack));
          if (config) SerialBT.println("TX AAN (RTTTL slot " + String(ringTrack) + ")");
          doTXEnable(1);
          if (config) SerialBT.flush();
          playSlot(ringBuf);
        }
      } else {
        byte mp3st = mp3.getStatus();
        if (mp3st != MP3_STATUS_PLAYING) {
          dbg("MP3 niet aan het spelen (status=" + String(mp3st) + "), start TX + playMP3");
          if (config) SerialBT.println("TX AAN");
          doTXEnable(1);
          playMP3(mp3track);
        }
      }
    }
  }

  if (config) handleMenu();
}

void doRandomFreq() {
  int randomFrequency = random(144000, 146000);
  randomFrequency = round(randomFrequency / 25.0) * 25;
  if (config) SerialBT.println("Willekeurige frequentie: " + String(randomFrequency / 1000) + "." + (randomFrequency % 1000 < 10 ? "0" : "") + (randomFrequency % 1000 < 100 ? "0" : "") + String(randomFrequency % 1000) + "MHz");
  setFreq(randomFrequency);
  dbg("Random freq: " + String(randomFrequency) + " kHz");
}

void doTXEnable(bool status) {
  if (status) {
    dbg("Zender INGESCHAKELD");
    digitalWrite(pin_LE, LOW);
    SPI.transfer(0x90);
    SPI.transfer(0x80);
    SPI.transfer(0x82);
    digitalWrite(pin_LE, HIGH);
    delay(50);
    digitalWrite(pin_LE, LOW);
    SPI.transfer(0x06);
    SPI.transfer(0x40);
    digitalWrite(pin_LE, HIGH);
    delay(50);
    if (terrormode) doRandomFreq(); else setFreq(frequency);
    digitalWrite(RF_TX, LOW);
  } else {
    dbg("Zender UITGESCHAKELD");
    digitalWrite(RF_TX, HIGH);
    mp3.stop();
    mp3.sleep();
  }
}

void setFreq(unsigned int frequency_kHz) {
  frequency_kHz /= 25;
  digitalWrite(pin_LE, LOW);
  SPI.transfer((frequency_kHz >> 8) & 0xFF) + 0x20;
  SPI.transfer(frequency_kHz & 0xFF);
  SPI.transfer(0x01);
  digitalWrite(pin_LE, HIGH);
  dbg("PLL ingesteld op " + String(frequency_kHz * 25) + " kHz");
}

void playMP3(unsigned int track) {
  if (track == 0) {
    if (numberoffiles == 1) {
      track = 1;
    } else {
      do {
        track = random(1, numberoffiles + 1);
      } while (track == previousTrack);
    }
  }

  mp3.playFileByIndexNumber(track);
  dbg("MP3 track " + String(track) + " gestart");
  mp3.play();
  previousTrack = track;
}

// === Morse code generator ====================================================
// 800 Hz toon op pin_Audio via LEDC. Tempo via WPM volgens de PARIS-norm
// (1 dot = 1200/wpm ms). Werkt onder arduino-esp32 2.x EN 3.x (ledc-API
// verschilt, vandaar de ifdefs - zelfde aanpak als panic-mode).

struct MorseEntry { char c; const char *code; };
static const MorseEntry morseTable[] = {
  {'A',".-"},   {'B',"-..."}, {'C',"-.-."}, {'D',"-.."},  {'E',"."},
  {'F',"..-."}, {'G',"--."},  {'H',"...."}, {'I',".."},   {'J',".---"},
  {'K',"-.-"},  {'L',".-.."}, {'M',"--"},   {'N',"-."},   {'O',"---"},
  {'P',".--."}, {'Q',"--.-"}, {'R',".-."},  {'S',"..."},  {'T',"-"},
  {'U',"..-"},  {'V',"...-"}, {'W',".--"},  {'X',"-..-"}, {'Y',"-.--"}, {'Z',"--.."},
  {'0',"-----"},{'1',".----"},{'2',"..---"},{'3',"...--"},{'4',"....-"},
  {'5',"....."},{'6',"-...."},{'7',"--..."},{'8',"---.."},{'9',"----."},
  {'/',"-..-."},{'?',"..--.."},{'.',".-.-.-"},{',',"--..--"},
  {'=',"-...-"},{'+',".-.-."},{'-',"-....-"}
};

const char* morseCode(char c) {
  if (c >= 'a' && c <= 'z') c -= 32;          // naar uppercase
  for (size_t i = 0; i < sizeof(morseTable)/sizeof(morseTable[0]); i++) {
    if (morseTable[i].c == c) return morseTable[i].code;
  }
  return nullptr;                              // onbekend teken -> overslaan
}

// Bereken totale duur in ms voor de gegeven tekst+snelheid (zonder echt te
// klinken). Gebruikt door de loop om de TX-on duur te bepalen wanneer txon=0.
unsigned long morseDurationMs(const char *text, byte wpm) {
  if (wpm < 3) wpm = 3; else if (wpm > 12) wpm = 12;
  unsigned long dotMs = 1200UL / wpm;
  unsigned long total = 0;
  bool firstChar = true;
  for (size_t i = 0; text[i]; i++) {
    char c = text[i];
    if (c == ' ') { total += dotMs * 7; firstChar = true; continue; }
    const char *code = morseCode(c);
    if (!code) continue;
    if (!firstChar) total += dotMs * 3;       // inter-letter gap
    firstChar = false;
    for (size_t j = 0; code[j]; j++) {
      if (j > 0) total += dotMs;              // inter-element gap
      total += (code[j] == '-') ? dotMs * 3 : dotMs;
    }
  }
  return total;
}

// Helpers: tone aan/uit en interrupteerbare delay (returns true = afbreken
// gevraagd door inkomende BT-input).
// Gemeenschappelijke duty-berekening voor morse én ringtone. morseAmp is een
// stap 1..10; we mappen op een smalle high-duty band die empirisch het beste
// klinkt op deze pieper-hardware: step N -> duty (100 - N)%, dus step 1 =
// 99% duty (smalste LOW-puls), step 10 = 90% duty. Bewust hoog-duty omdat
// de modulator-keten daar de luidste tonen geeft.
static uint32_t toneDuty() {
  uint32_t pct = (morseAmp >= 1 && morseAmp <= 10) ? (100UL - morseAmp) : 95UL;
  return pct * 256UL / 100UL;
}

static inline void morseToneOn() {
#if ESP_ARDUINO_VERSION_MAJOR >= 3
  ledcWrite(pin_Audio, toneDuty());
#else
  ledcWrite(0, toneDuty());
#endif
}
static inline void morseToneOff() {
#if ESP_ARDUINO_VERSION_MAJOR >= 3
  ledcWrite(pin_Audio, 0);
#else
  ledcWrite(0, 0);
#endif
}
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

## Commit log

2025-04-22 Upload Kicad files
    [2m pieper THT.kicad_pcb, 2m pieper THT.kicad_sch, PT-10.stp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]
2025-04-25 Update data
    [2m pieper THT.kicad_pcb, 2m pieper THT.kicad_sch]
